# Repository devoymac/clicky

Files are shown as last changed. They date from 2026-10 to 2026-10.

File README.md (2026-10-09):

# Clicky

A portable, battery-powered heart-shaped "pet" in the style of STΛRBOY / Lil
Guy: a round animated eye, a personality driven by sensors, and a touch button
to pet it — it blushes when you give it affection. It runs on a single LiPo
battery and charges through the same USB-C port it uses to program.

## What it is

Clicky is a small companion you wear on your clothes or bag. Inside a
3D-printed heart lives a round screen that acts as its eye, and a set of
sensors give it a personality: it gets dizzy when you shake it, shivers when
it's cold, startles at loud noises, and falls asleep if you ignore it. Touch
it and it wakes up happy. It remembers its state across power-off.

## Design goals

- **Portable and battery-powered** — one small LiPo cell, no wall power.
- **Long battery life** — low-power sleeps, dimmed display when drowsy.
- **A living personality** — reacts to shake, cold, sound, and touch.
- **An original touch** — the heart blushes when you pet it.
- **Built by hand** — hand-wired to a tiny module, no complex PCB.

## Hardware

### Brain: Seeed XIAO ESP32-C3

A thumb-sized module with a built-in LiPo charger, WiFi/BLE, and plenty of
GPIOs, chosen over the nRF52840 for its lower cost and simplicity:

- **Built-in LiPo charger** — no external charging IC required. Plug in USB-C
  to charge; unplug to run on battery. Automatic.
- **WiFi + BLE** — headroom for a future phone companion or notifications.
- **USB-C** — programming and charging share the same port.
- **Low-power sleep** — dozes in µA range, waking on the touch button.

### The eye: GC9A01 1.28" round display

A 240x240 round SPI display that shows Clicky's expressions. Note: the
chosen module has no separate backlight pin — the backlight is tied to 3V3
internally, so the firmware should put the display to sleep instead of just
dimming it, to save battery when it dozes.

### The personality (sensors)

- **MPU-6000** (motion) — shake and tilt: dizzy, angry, look-downhill.
- **DS18B20** (temperature) — cold: shiver, then freeze with a blue tint.
- **MAX4466** (microphone amp) — loud sounds: startled, nervous.

### Interaction

- One tactile push button — pet the heart, it blushes and wakes up.

### Power

- A small certified LiPo (~320 mAh, e.g. 402535) with built-in protection,
  charged through the XIAO's own USB-C. Verify polarity before soldering
  (red = +, black = -).

## Schematic (current state)

The KiCad schematic is complete and validated by ERC. All nets are connected:
power (3V3/GND), I2C (MPU), 1-Wire (DS18B20 with 4.7k pull-up), SPI (display),
the microphone, the pet button, and the battery (VBAT). The remaining ERC
notices are intentional free pins and CLI false positives.

Note: some component footprints still need fixing before moving to PCB
(R1, J1, SW1, J2, J3, C1, C2 use default/placeholder footprints).

## Wiring quick reference

- Battery + → XIAO VBAT ; battery - → GND (via JST-PH 2.0).
- Display GC9A01 (7-pin): VCC→3V3, GND→GND, SCL→D8 (SCK), SDA→D10 (MOSI),
  DC→D6, CS→D3, RST→3V3.
- MPU-6000 (I2C): VDD→3V3, GND→GND, SDA→D4, SCL→D5, AD0→GND, CPOUT→100nF
  to GND, REGOUT→100nF to GND.
- DS18B20: VDD→3V3, GND→GND, DQ→D6 + 4.7kΩ pull-up to 3V3.
- Mic MAX4466: VCC→3V3, GND→GND, OUT→D1.
- Pet button: one pin→D0, other→GND.

## Firmware (planned)

Sensor-driven moods driven by simple timestamps (last interaction, timeout to
doze/sleep) plus sensor triggers. Libraries: TFT_eSPI (display), Adafruit
MPU6050 + Unified Sensor, DallasTemperature + OneWire, ADC for the mic.

## Bill of Materials

See [BOM.md](BOM.md) for the full parts list with prices (~$60 parts).

## Status

- [x] Architecture decided (heart-shaped pet, ESP32-C3, sensors + touch)
- [x] BOM finalized (~$60)
- [x] Schematic wired and ERC-validated
- [ ] Fix remaining component footprints (R1, J1, SW1, J2, J3, C1, C2)
- [ ] PCB layout
- [ ] 3D heart shell (OpenSCAD)
- [ ] Firmware

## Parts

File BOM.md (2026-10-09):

# Cliky – bill of materials

<!-- Generated by Half Life from project cmuur6jf409qe01smoq3ujl5z. Edits here are overwritten on the next sync. -->
<!-- Generated: 2026-10-09T20:39:36.242Z -->

> [!NOTE]
> This parts list is mirrored from [Half Life](https://halflife.hackclub.com). Editing it here will not change the platform's copy, and the next sync overwrites this file.

| Week | Tier | Parts funding |
| --- | --- | --- |
| Week 1 | Tier 2 | $65.00 |

| Part | What it's for | Qty | Unit | Total | Vendor |
| --- | --- | --- | --- | --- | --- |
| [XIAO-ESP32-C3-SMD](https://www.seeedstudio.com/Seeed-XIAO-ESP32C3-p-5431.html) | MCU with built-in LiPo charger and WiFi/BLE | 1 | $4.99 | $4.99 | [Seeed Studio](https://www.seeedstudio.com/Seeed-XIAO-ESP32C3-p-5431.html) |
| [MPU-6000](https://www.aliexpress.us/item/3256808332288788.html) | 6-axis accel/gyro (shake and tilt) | 1 | $1.88 | $1.88 | [InvenSense](https://www.aliexpress.us/item/3256808332288788.html) |
| [DS18B20](https://www.lcsc.com/product-detail/C376006.html) | Temperature sensor (cold detection) | 1 | $0.58 | $0.58 | [Maxim (UMW)](https://www.lcsc.com/product-detail/C376006.html) |
| [Conn_01x02_Pin](https://www.aliexpress.us/item/3256805611374476.html) | Battery connector (JST-PH 2.0) | 1 | $0.50 | $0.50 | [Generic](https://www.aliexpress.us/item/3256805611374476.html) |
| [GC9A01 1.28in round TFT (7-pin)](https://www.aliexpress.us/item/3256808098235758.html) | Round animated-eye display (240x240, SPI) | 1 | $4.48 | $4.48 | [GC9A01](https://www.aliexpress.us/item/3256808098235758.html) |
| [MAX4466 mic (3-pin)](https://www.aliexpress.us/item/3256805885526362.html) | Electret mic amplifier (sound detection) | 1 | $1.74 | $1.74 | [MAX4466](https://www.aliexpress.us/item/3256805885526362.html) |
| [4.7k](https://lcsc.com/product-detail/Carbon-Film-Resistors_4-7KR-472-5_C120071.html) | DS18B20 OneWire pull-up | 1 | $0.01 | $0.01 | [Generic](https://lcsc.com/product-detail/Carbon-Film-Resistors_4-7KR-472-5_C120071.html) |
| [100nF](https://www.aliexpress.us/item/3256807718543888.html) | MPU-6000 CPOUT decoupling | 1 | $0.05 | $0.05 | [Generic](https://www.aliexpress.us/item/3256807718543888.html) |
| [100nF](https://www.aliexpress.us/item/3256807718543888.html) | MPU-6000 REGOUT decoupling | 1 | $0.05 | $0.05 | [Generic](https://www.aliexpress.us/item/3256807718543888.html) |
| [SW_Push](https://www.aliexpress.us/item/3256807751442375.html) | Tactile pet/wake button | 1 | $0.10 | $0.10 | [Generic](https://www.aliexpress.us/item/3256807751442375.html) |
| [LiPo 402535 3.7V 320mAh](https://www.amazon.com/dp/B08215N9R8) | Battery cell (certified, with protection) | 1 | $9.99 | $9.99 | [EEMB](https://www.amazon.com/dp/B08215N9R8) |
| [30AWG silicone wire (5 colors)](https://www.aliexpress.us/item/3256808281675998.html) | Internal wiring | 1 | $6.96 | $6.96 | [Generic](https://www.aliexpress.us/item/3256808281675998.html) |
| [Prototype board 5x7cm 1.2mm](https://www.aliexpress.us/item/3256807718543888.html) | Solder modules onto (cut to circle) | 1 | $0.43 | $0.43 | [Generic](https://www.aliexpress.us/item/3256807718543888.html) |
| [PETG filament 1.75mm 1kg](https://www.aliexpress.us/item/3256812523172305.html) | 3D-printed heart shell | 1 | $14.81 | $14.81 | [Creality](https://www.aliexpress.us/item/3256812523172305.html) |
| [Plastic primer + chrome spray](https://www.amazon.com/dp/B003CT498U) | Chrome finish (optional) | 1 | $13.44 | $13.44 | [Rust-Oleum](https://www.amazon.com/dp/B003CT498U) |
| **Parts subtotal** | — | — | — | **$60.01** | — |
| **Tax & shipping** | — | — | — | **$0.00** | — |
| **Total** | — | — | — | **$60.01** | — |

$4.99 left of the tier's funding.

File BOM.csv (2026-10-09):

Reference | Value | Footprint | Quantity | Description | Manufacturer | Part Number | Supplier | Unit Price (USD) | Link
U1 | XIAO-ESP32-C3-SMD | Seeed_Studio_XIAO_Series:XIAO-ESP32-C3-SMD | 1 | MCU with built-in LiPo charger and WiFi/BLE | Seeed Studio | XIAO ESP32-C3 | Seeed Studio | 4.99 | https://www.seeedstudio.com/Seeed-XIAO-ESP32C3-p-5431.html
U2 | MPU-6000 | Sensor_Motion:InvenSense_QFN-24_4x4mm_P0.5mm | 1 | 6-axis accel/gyro (shake and tilt) | InvenSense | MPU-6000 (module GY-521) | AliExpress | 1.88 | https://www.aliexpress.us/item/3256808332288788.html
U3 | DS18B20 | Package_TO_SOT_THT:TO-92_Inline | 1 | Temperature sensor (cold detection) | Maxim (UMW) | DS18B20 | LCSC | 0.58 | https://www.lcsc.com/product-detail/C376006.html
J1 | Conn_01x02_Pin | Connector_PinHeader_2.54mm:PinHeader_1x02_P2.54mm_Vertical | 1 | Battery connector (JST-PH 2.0) | Generic | JST-PH 2.0 | AliExpress | 0.50 | https://www.aliexpress.us/item/3256805611374476.html
J2 | GC9A01 1.28in round TFT (7-pin) | Connector_PinHeader_2.54mm:PinHeader_1x07_P2.54mm_Vertical | 1 | Round animated-eye display (240x240, SPI) | GC9A01 | GC9A01 1.28 round | AliExpress | 4.48 | https://www.aliexpress.us/item/3256808098235758.html
J3 | MAX4466 mic (3-pin) | Connector_PinHeader_2.54mm:PinHeader_1x03_P2.54mm_Vertical | 1 | Electret mic amplifier (sound detection) | MAX4466 | MAX4466 module | AliExpress | 1.74 | https://www.aliexpress.us/item/3256805885526362.html
R1 | 4.7k | Resistor_THT:R_Axial_DIN0207_L6.3mm_D2.5mm_P10.16mm_Horizontal | 1 | DS18B20 OneWire pull-up | Generic | 4.7k 1/4W | LCSC | 0.01 | https://lcsc.com/product-detail/Carbon-Film-Resistors_4-7KR-472-5_C120071.html
C1 | 100nF | Capacitor_SMD:C_0603_1608Metric | 1 | MPU-6000 CPOUT decoupling | Generic | 100nF 0603 | AliExpress | 0.05 | https://www.aliexpress.us/item/3256807718543888.html
C2 | 100nF | Capacitor_SMD:C_0603_1608Metric | 1 | MPU-6000 REGOUT decoupling | Generic | 100nF 0603 | AliExpress | 0.05 | https://www.aliexpress.us/item/3256807718543888.html
SW1 | SW_Push | Button_Switch_THT:SW_Push_6mm | 1 | Tactile pet/wake button | Generic | 6x6mm tactile | AliExpress | 0.10 | https://www.aliexpress.us/item/3256807751442375.html
- | LiPo 402535 3.7V 320mAh | n/a | 1 | Battery cell (certified, with protection) | EEMB | 402535 320mAh | Amazon | 9.99 | https://www.amazon.com/dp/B08215N9R8
- | 30AWG silicone wire (5 colors) | n/a | 1 | Internal wiring | Generic | 30AWG | AliExpress | 6.96 | https://www.aliexpress.us/item/3256808281675998.html
- | Prototype board 5x7cm 1.2mm | n/a | 1 | Solder modules onto (cut to circle) | Generic | 5x7cm protoboard | AliExpress | 0.43 | https://www.aliexpress.us/item/3256807718543888.html
- | PETG filament 1.75mm 1kg | n/a | 1 | 3D-printed heart shell | Creality | PETG 1kg | AliExpress | 14.81 | https://www.aliexpress.us/item/3256812523172305.html
- | Plastic primer + chrome spray | n/a | 1 | Chrome finish (optional) | Rust-Oleum | Primer + chrome | Amazon | 13.44 | https://www.amazon.com/dp/B003CT498U

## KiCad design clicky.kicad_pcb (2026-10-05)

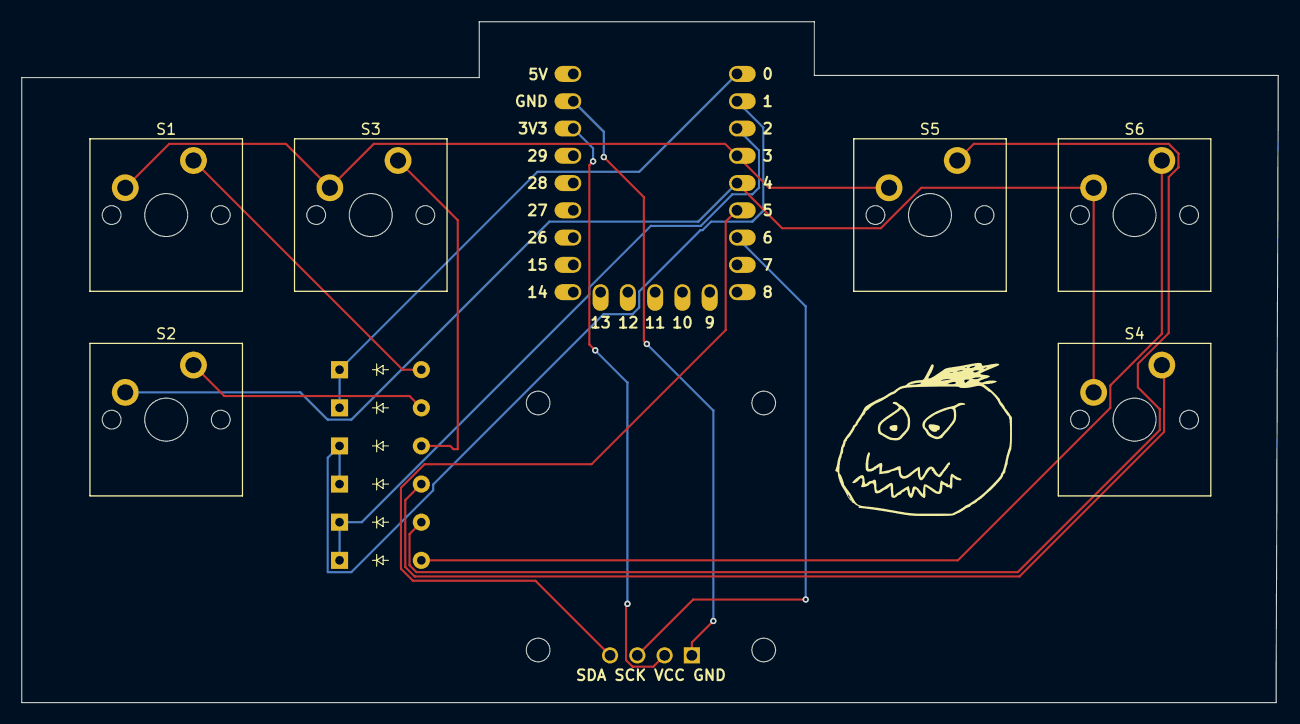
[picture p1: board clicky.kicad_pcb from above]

Board: 2 copper layers, 117.0 x 63.4 mm, 14 parts (0 on the bottom side), 15 nets.

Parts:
D1, D2, D3, D4, D5, D6: Diode_DO-35
J1: OLED_128x64
S1, S2, S3, S4, S5, S6: MX_PCB_1.00u
U1: RP2040_Zero

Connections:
/colum 0: S1.1, S3.1, S5.1, U1.4 (3)
/colum 1: S2.1, S4.1, S6.1, U1.5 (4)
/row 0: D1.1 (K), D2.1 (K), U1.1 (0)
/row 1: D3.1 (K), D4.1 (K), U1.2 (1)
/row 2: D5.1 (K), D6.1 (K), U1.3 (2)
unnamed: D1.2 (A), S1.2
unnamed: D2.2 (A), S2.2
unnamed: D3.2 (A), S3.2
unnamed: D4.2 (A), S4.2
unnamed: D5.2 (A), S5.2
unnamed: D6.2 (A), S6.2
unnamed: J1.1 (GND), U1.22 (GND)
unnamed: J1.3 (SCL), U1.7 (6)
unnamed: J1.4 (SDA), U1.6 (5)
unnamed: J1.2 (VCC), U1.21 (3V3)

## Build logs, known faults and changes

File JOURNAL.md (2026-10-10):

# Cliky – devlog

<!-- Generated by Half Life from project cmuur6jf409qe01smoq3ujl5z. Edits here are overwritten on the next sync. -->
<!-- Generated: 2026-10-10T16:21:45.051Z -->

> [!NOTE]
> This devlog is mirrored from [Half Life](https://halflife.hackclub.com). Editing it here will not change the platform's copy, and the next sync overwrites this file.

> A PCB tu play cookie clicker

| Week | Tier | Hours logged | Entries |
| --- | --- | --- | --- |
| Week 1 | Tier 2 | 11h | 6 |

## Contents

1. [2026-10-05 – I started by making the schematic and wiring everything together all the connections, the nets, everything joined up in one logical diagram.![image](https://halflife.hackclub-assets.com/hackclub-half-](#2026-10-05-i-started-by-making-the-schematic-and-wiring-ever)
2. [2026-10-06 – I've decided to change the components of the project relative to the current schematic (which still uses the RP2040-Zero). The decision is made and documented here.![image](https://halflife.hackclub-a](#2026-10-06-ive-decided-to-change-the-components-of-the-proje)
3. [2026-10-07 – Today the project took a](#2026-10-07-imagehttpshalflifehackclub-assetscomhackclub-half)
4. [2026-10-08 – So I've been drawing thi](#2026-10-08-imagehttpshalflifehackclub-assetscomhackclub-half)
5. [2026-10-09 – ](#2026-10-09-imagehttpshalflifehackclub-assetscomhackclub-half)
6. [2026-10-10 – ](#2026-10-10-imagehttpshalflifehackclub-assetscomhackclub-half)

## Design

### 2026-10-05 – I started by making the schematic and wiring everything together all the connections, the nets, everything joined up in one logical diagram.![image](https://halflife.hackclub-assets.com/hackclub-half-

**2h**

I started by making the schematic and wiring everything together all the connections, the nets, everything joined up in one logical diagram.
the PCB. I took all those footprints and placed them physically, got them arranged where I wanted, and then routed the traces to match the connections I'd already defined. Finally I double checked that everything was placed and routed correctly before calling it done.
And on top of all that, I'm also thinking about making it portable. adding a battery so I can take it around without plugging in. That's the part I'm still figuring out, but that's the direction I want to go.

### 2026-10-06 – I've decided to change the components of the project relative to the current schematic (which still uses the RP2040-Zero). The decision is made and documented here.![image](https://halflife.hackclub-a

**2h**

I've decided to change the components of the project relative to the current schematic (which still uses the RP2040-Zero). The decision is made and documented here.
Consequences of the change : hardware gets simpler


### 2026-10-07 – Today the project took a

**2h**

Today the project took a complete turn, and for a good reason: I realized I didn't want an accessory, I wanted a pet. Something you wear, that has a little face, that reacts to you. So Clicky went from being "a weird keyboard" to being a small heart that lives with you.



### 2026-10-08 – So I've been drawing thi

**2h**

So I've been drawing this schematic in KiCad, and honestly it's going a lot better than I expected. I got the little ESP32-C3 brain in, the motion sensor, the temperature one, the resistor, the pet button, and the battery hookup. And I figured out the net-label thing — calling wires the same name connects them, which is way cleaner than a mess of crossing lines. So 3V3, ground, the I2C lines, the temp wire, the touch button, and the battery are all in.

But then I hit a wall, the round screen (GC9A01) and the mic just don't show up when I search for them. Turns out they're not in any library because you buy them as little modules already made. The fix is to draw them as generic connectors or just make my own symbol

### 2026-10-09 – 

**1h**


Today I kept working on the KiCad schematic for Clicky. A lot of small steps, but they added up: I ran KiCad's ERC over and over to find problems, and I fixed them one by one.
I also learned the hard way that a few components had wrong footprints: KiCad was matching a radio connector to the battery, a lever switch to the touch button, and the XIAO's footprint wasn't even being found because I'd given the library the wrong name. I fixed the library name and the footprint now resolves.

### 2026-10-10 – 

**2h**


Today I finished the layout of Clicky's PCB. I'd already placed all the components and routed most of the traces, so today I went back and cleaned up what the DRC  was flagging.
I'm starting to model the 3D-printed heart shell — the actual body of Clicky, the part that makes it a heart instead of just a board.

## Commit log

2026-10-06 Add BOM and project README (nRF52840 architecture)
2026-10-07 Update BOM for heart-shaped pet (ESP32-C3 + GC9A01 + sensors)
    [BOM.csv]
2026-10-09 Fix BOM.csv to standard BOM format; update README and BOM for heart-shaped pet design
    [BOM.csv]
2026-10-11 Scaffold Arduino firmware, add board render and fix wiring
    - firmware/: Arduino IDE scaffold (clicky.ino mood state machine, pins.h,
    moods.h), TFT_eSPI GC9A01 setup, and Arduino IDE setup guide. Compiles
    clean for the XIAO ESP32-C3.
    - assets/: single 2D capture of the fully-placed PCB, shown in the README.
    - README: board preview image; correct DS18B20 pin (D7, not D6) derived
    from the schematic netlist; firmware + status updates.
    - .gitignore: exclude history plugin state and regenerable KiCad exports.
2026-10-11 Add Gerber export for Clicky PCB (current layout, RC1)
2026-10-11 Fix DS18B20 pull-up: R1 now pulls DQ to 3V3 (was GND); re-export Gerber
2026-10-11 Update README: add schematic & PCB images, drop Status section; commit R1 pull-up fix sources
